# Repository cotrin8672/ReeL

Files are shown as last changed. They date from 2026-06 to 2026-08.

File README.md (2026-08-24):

# ReeL

Hardware sources and manufacturing assets for the ReeL split keyboard.

The RMK firmware, Vial definition, trackball profiler, and firmware build
workflow live in [rmk-config-ReeL](https://github.com/cotrin8672/rmk-config-ReeL).

## Repository layout

- `pcb/`: KiCad projects, project-local symbol and footprint libraries, and the PMW3610 breakout manufacturing package
- `model/`: mechanical STEP and STL models
- `fabrication/gerber/`: generated Gerber and drill outputs for the main left and right PCBs
- `docs/materials/`: component research and supporting material documents

The firmware repository was split from hardware commit
`b9bacc7681b5a1461f23b08cf7a2b1b867c73b0e`.

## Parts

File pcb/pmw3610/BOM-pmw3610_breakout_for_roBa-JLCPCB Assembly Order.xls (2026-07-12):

JLCPCB BOM Tool - BOM Matching
BOM name：BOM-pmw3610_breakout_for_roBa-JLCPCB Assembly Order.xlsx |  |  | Download Time：2026-07-12 19:56:11 |  |  |  | * Our matching results are updated in real-time, but stock and prices may change. If it's been over 24 hours, please re-match before placing your order.
PCB Assembled Qty：5 |  |  | Est. Total Price：3.9725
Your BOM |  |  |  |  | Matched Parts |  |  |  |  |  |  | Order Information
Top Designator | Bottom Designator | Comment | Footprint | JLCPCB Part # | Matches | Part # | Manufacturer | Footprint | Description | Category | Warning | JLCPCB Part # | Product link | Lib Type | Qty | Source | Total Price ($)
 | C1,C2 | 1u | C_0603_1608Metric |  | Select by System | CL10A105KB8NNNC | Samsung Electro-Mechanics | 0603 | 1uF 50V X5R ±10% 0603 Multilayer Ceramic Capacitors MLCC - SMD/SMT ROHS | Multilayer Ceramic Capacitors MLCC - SMD/SMT |  | C15849 | https://jlcpcb.com/partdetail/16531-CL10A105KB8NNNC/C15849 | Basic | 10 | 10 JLCPCB | 0.276
 | C3,C8 | 100n | C_0603_1608Metric |  | Unconfirmed | CC0603KRX7R9BB104 | YAGEO | 0603 | 100nF 50V X7R ±10% 0603 Multilayer Ceramic Capacitors MLCC - SMD/SMT ROHS | Multilayer Ceramic Capacitors MLCC - SMD/SMT | 1.Multiple lines in the BOM have been matched to the same part. Please check if the matching is correct. ; | C14663 | https://jlcpcb.com/partdetail/YAGEO-CC0603KRX7R9BB104/C14663 | Basic | 15 | 15 JLCPCB | 0.402
 | C5 | 100n(X7R) | C_0603_1608Metric |  | Unconfirmed | CC0603KRX7R9BB104 | YAGEO | 0603 | 100nF 50V X7R ±10% 0603 Multilayer Ceramic Capacitors MLCC - SMD/SMT ROHS | Multilayer Ceramic Capacitors MLCC - SMD/SMT | 1.Multiple lines in the BOM have been matched to the same part. Please check if the matching is correct. ; | C14663 | https://jlcpcb.com/partdetail/YAGEO-CC0603KRX7R9BB104/C14663 | Basic | 15 | 15 JLCPCB | 0.402
 | C4 | 10n | C_0603_1608Metric |  | Unconfirmed | 0603B103K500NT | FH (Guangdong Fenghua Advanced Tech) | 0603 | 10nF 50V X7R ±10% 0603 Multilayer Ceramic Capacitors MLCC - SMD/SMT ROHS | Multilayer Ceramic Capacitors MLCC - SMD/SMT | 1.Multiple lines in the BOM have been matched to the same part. Please check if the matching is correct. ; | C57112 | https://jlcpcb.com/partdetail/58143-0603B103K500NT/C57112 | Basic | 10 | 10 JLCPCB | 0.271
 | C7 | 10n(X7R) | C_0603_1608Metric |  | Unconfirmed | 0603B103K500NT | FH (Guangdong Fenghua Advanced Tech) | 0603 | 10nF 50V X7R ±10% 0603 Multilayer Ceramic Capacitors MLCC - SMD/SMT ROHS | Multilayer Ceramic Capacitors MLCC - SMD/SMT | 1.Multiple lines in the BOM have been matched to the same part. Please check if the matching is correct. ; | C57112 | https://jlcpcb.com/partdetail/58143-0603B103K500NT/C57112 | Basic | 10 | 10 JLCPCB | 0.271
 | C6 | 10u(X7R) | C_0603_1608Metric |  | Select by System | CL10A106MA8NRNC | Samsung Electro-Mechanics | 0603 | 10uF 25V X5R ±20% 0603 Multilayer Ceramic Capacitors MLCC - SMD/SMT ROHS | Multilayer Ceramic Capacitors MLCC - SMD/SMT |  | C96446 | https://jlcpcb.com/partdetail/97651-CL10A106MA8NRNC/C96446 | Basic | 5 | 5 JLCPCB | 0.6935
 | C9 | 3.3u/25V | C_0603_1608Metric |  | Select by Customer | CL10A475KO8NNNC | Samsung Electro-Mechanics | 0603 | 16V 4.7uF X5R ±10% 0603 Multilayer Ceramic Capacitors MLCC - SMD/SMT ROHS | Multilayer Ceramic Capacitors MLCC - SMD/SMT |  | C19666 | https://jlcpcb.com/partdetail/20375-CL10A475KO8NNNC/C19666 | Basic | 5 | 5 JLCPCB | 0.5615
 | R1 | 2M | R_0603_1608Metric |  | Select by System | 0603WAF2004T5E | UNI-ROYAL(Uniroyal Elec) | 0603 | -55℃~+155℃ 100mW 2MΩ 75V Thick Film Resistor ±1% ±100ppm/℃ 0603 Chip Resistor - Surface Mount ROHS | Chip Resistor - Surface Mount |  | C22976 | https://jlcpcb.com/partdetail/23703-0603WAF2004T5E/C22976 | Basic | 5 | 5 JLCPCB | 0.014
 | U1 | MCP1700T-1802E/TT | SOT-23 |  | Select by Customer | MCP1700T-1802E/TT(MS) | MSKSEMI | SOT-23 | -40℃~+125℃@(Tj) 1 1.8V 280mV@(300mA) 2uA 300mA 5.5V Fixed Over Current Protection、Over Temperature Protection Positive SOT-23 Voltage Regulators - Linear, Low Drop Out (LDO) Regulators ROHS | Voltage Regulators - Linear, Low Drop Out (LDO) Regulators |  | C20627192 | https://jlcpcb.com/partdetail/MSKSEMI-MCP1700T_1802E_TT_MS/C20627192 | Extended | 7 | 7 JLCPCB | 1.0815

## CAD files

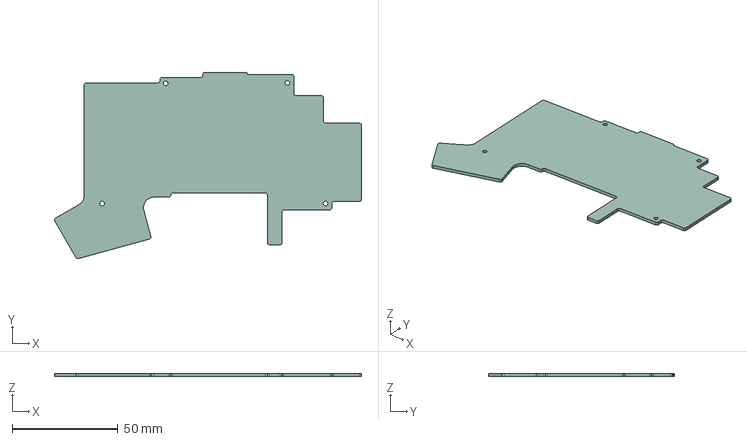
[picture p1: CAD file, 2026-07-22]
hardware/models/reel-right-bottom.step
145.0 x 88.1 x 1.55 mm

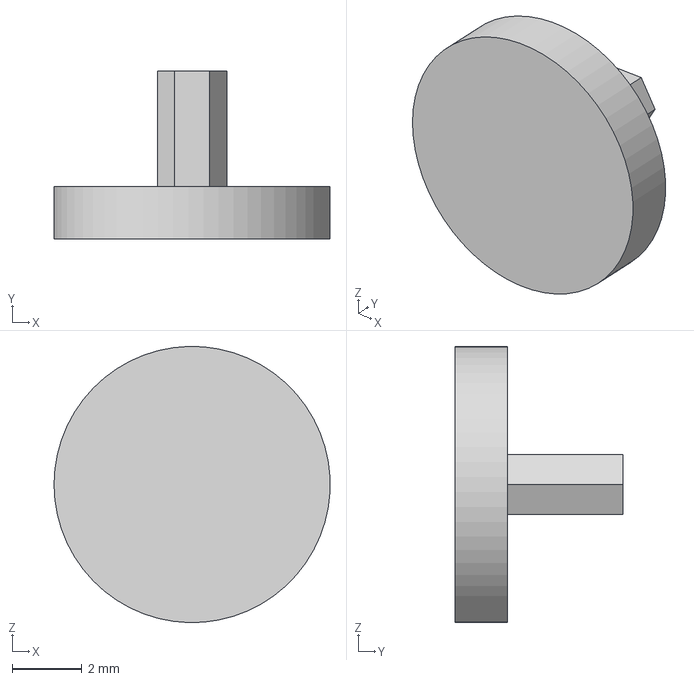
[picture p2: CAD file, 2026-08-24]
model/encoder_knob_3.3.step
7.89 x 4.80 x 7.90 mm

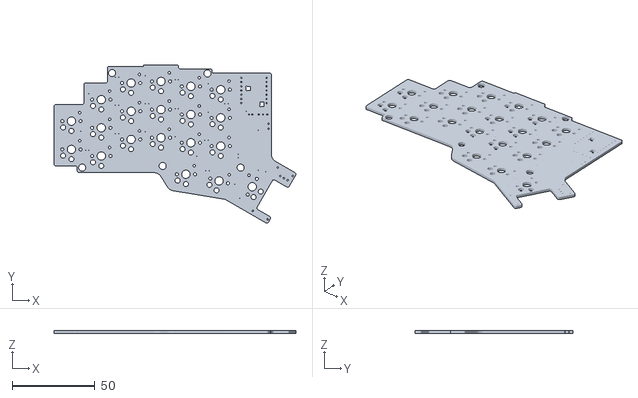
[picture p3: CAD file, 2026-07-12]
pcb/left/ReeL_left.stl
145.9 x 95.5 x 1.60

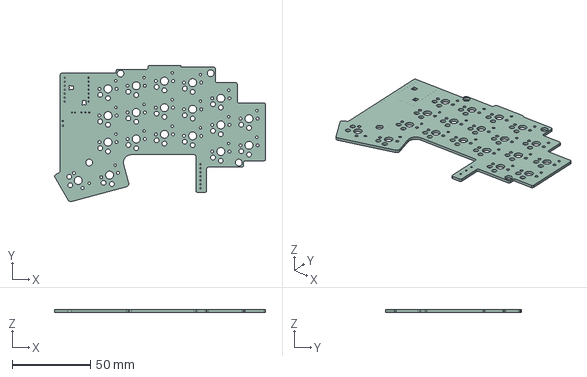
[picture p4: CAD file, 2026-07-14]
pcb/right/ReeL_right.step
134.6 x 86.9 x 1.60 mm

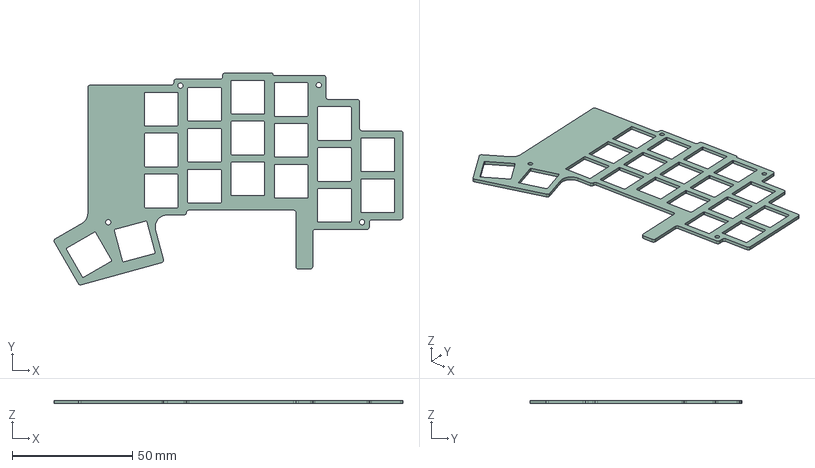
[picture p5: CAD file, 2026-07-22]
hardware/models/reel-right-top.step
145.0 x 88.1 x 1.45 mm

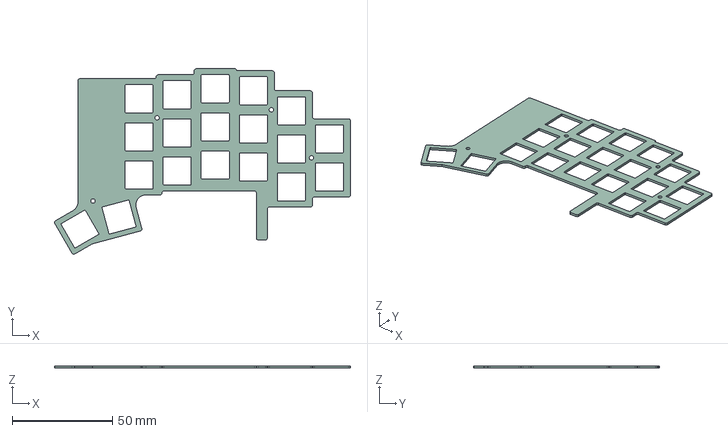
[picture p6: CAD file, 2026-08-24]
model/reel_right_top.step
147.7 x 92.6 x 1.20 mm

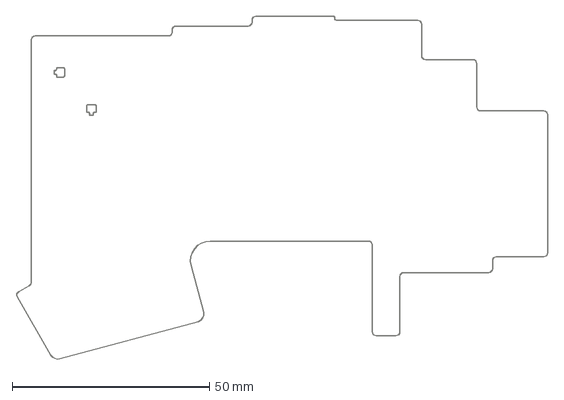
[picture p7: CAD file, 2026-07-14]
pcb/right/reel-right-Edge_Cuts.dxf
134.8 x 87.1 mm

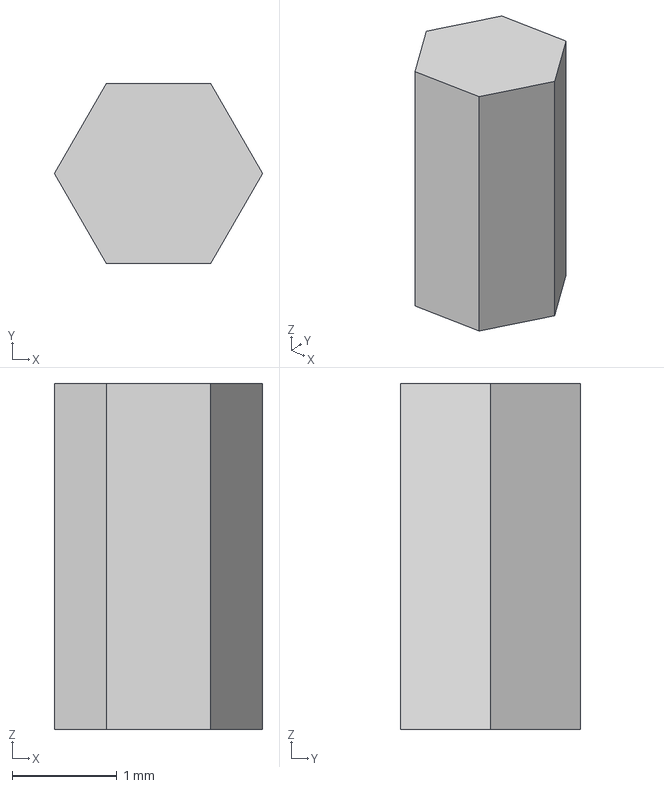
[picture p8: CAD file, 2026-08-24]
model/encoder_pole.step
1.99 x 1.72 x 3.30 mm

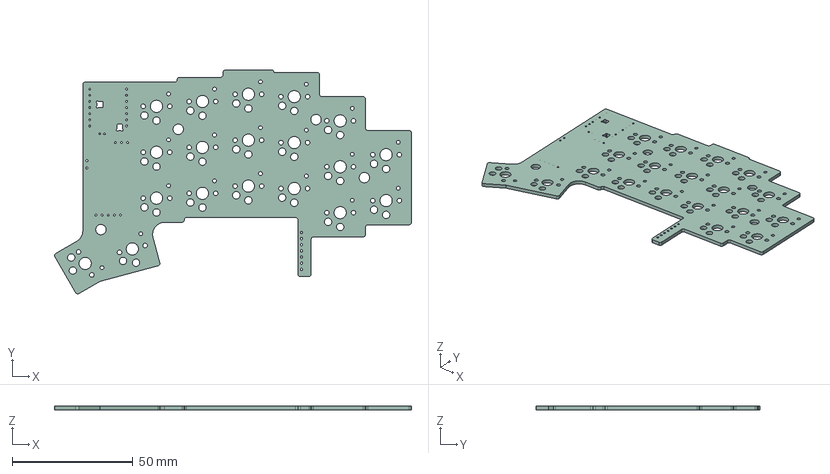
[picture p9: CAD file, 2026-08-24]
model/reel_right.step
147.7 x 92.6 x 1.60 mm

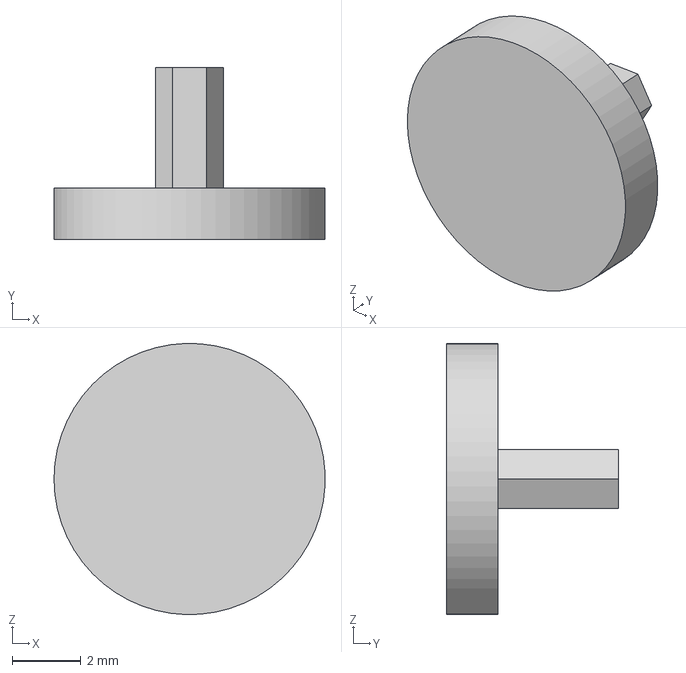
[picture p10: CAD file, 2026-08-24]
model/encoder_knob.step
7.89 x 5.00 x 7.90 mm

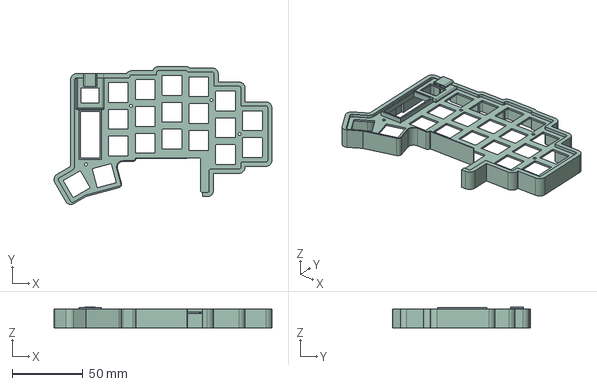
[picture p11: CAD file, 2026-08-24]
model/reel_right_sw.step
154.5 x 97.8 x 14.6 mm

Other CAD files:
pcb/right_bottom/reel_right_bottom.stl
pcb/right_top/reel_right_top.stl
model/reel_right_top_neo.step
model/RotaryEncoderTest.stl
model/TrackballCase.stl
model/encoder_shaft.step
model/reel_left.step
model/reel_left_bottom.step
model/reel_left_top.step
model/reel_right_bottom.step
model/reel_right_top_neo2.step
pcb/right/ReeL_right.stl

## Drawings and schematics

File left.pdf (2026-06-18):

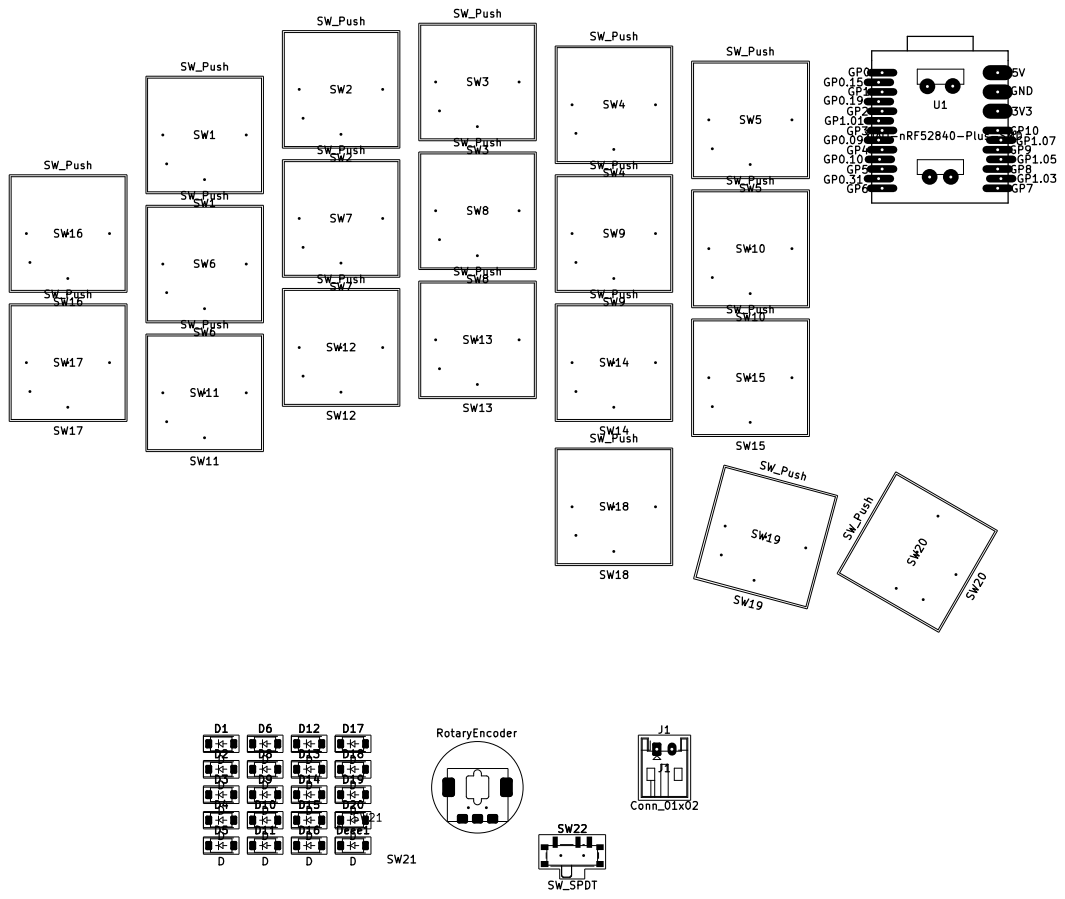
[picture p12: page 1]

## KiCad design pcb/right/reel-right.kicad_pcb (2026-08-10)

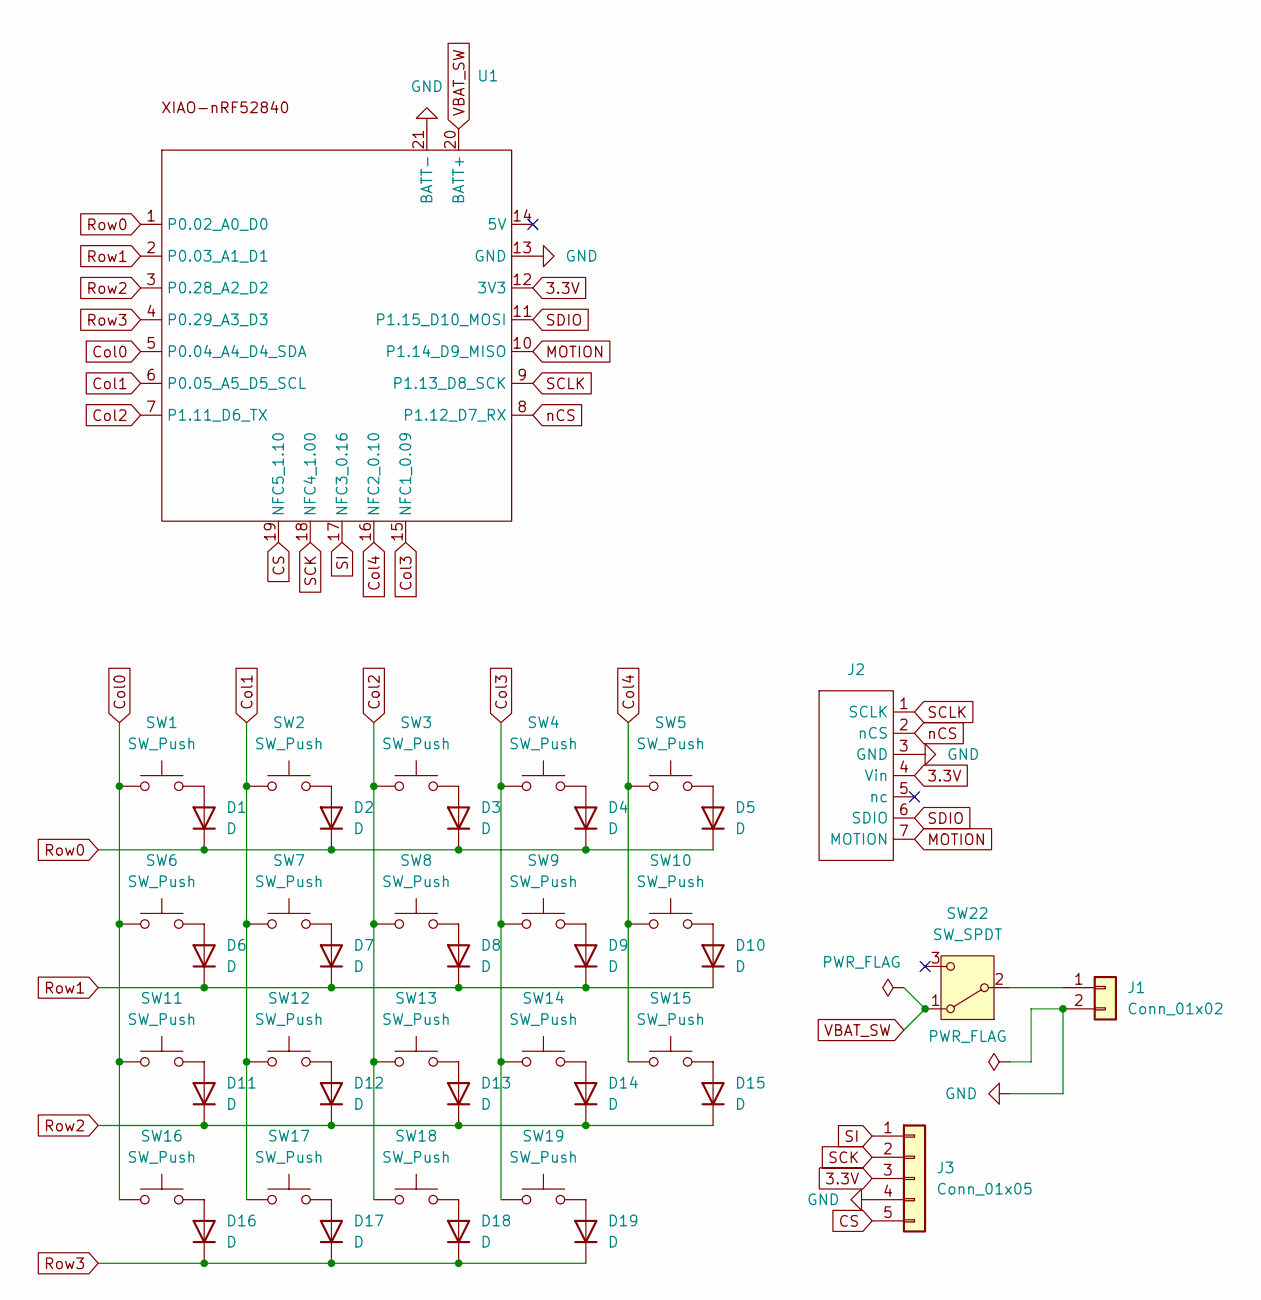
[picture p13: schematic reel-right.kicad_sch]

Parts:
D1, D2, D3, D4, D5, D6, D7, D8, D9, D10, D11, D12, D13, D14, D15, D16, D17, D18, D19: D; Diode_SMD
J1: Conn_01x02; JST_PH_S2B-PH-K_1x02_P2.00mm_Horizontal
J2: pmw3610_connector
J3: Conn_01x05; Display_BeeKeeb_MIP_1.08in_LS011B7DH03
SW1, SW2, SW3, SW4, SW5, SW6, SW7, SW8, SW9, SW10, SW11, SW12, SW13, SW14, SW15, SW16, SW17, SW18, SW19: SW_Push; SW_Hotswap_Kailh_Choc_V1V2_1.00u
SW22: SW_SPDT; SW_SPDT_PCM12
U1: XIAO_nRF52840_wBAT_wNFC_1

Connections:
3.3V: J2.4 (Vin), J3.3, U1.12 (3V3)
CS: J3.5, U1.19 (NFC5_1.10)
Col0: SW1.1, SW6.1, SW11.1, SW16.1, U1.5 (P0.04_A4_D4_SDA)
Col1: SW2.1, SW7.1, SW12.1, SW17.1, U1.6 (P0.05_A5_D5_SCL)
Col2: SW3.1, SW8.1, SW13.1, SW18.1, U1.7 (P1.11_D6_TX)
Col3: SW4.1, SW9.1, SW14.1, SW19.1, U1.15 (NFC1_0.09)
Col4: SW5.1, SW10.1, SW15.1, U1.16 (NFC2_0.10)
GND: J1.2, J2.3 (GND), J3.4, U1.13 (GND), U1.21 (BATT-)
MOTION: J2.7 (MOTION), U1.10 (P1.14_D9_MISO)
unnamed: D1.2 (A), SW1.2
unnamed: D2.2 (A), SW2.2
unnamed: D3.2 (A), SW3.2
unnamed: D4.2 (A), SW4.2
unnamed: D5.2 (A), SW5.2
unnamed: D6.2 (A), SW6.2
unnamed: D7.2 (A), SW7.2
unnamed: D8.2 (A), SW8.2
unnamed: D9.2 (A), SW9.2
unnamed: D10.2 (A), SW10.2
unnamed: D11.2 (A), SW11.2
unnamed: D12.2 (A), SW12.2
unnamed: D13.2 (A), SW13.2
unnamed: D14.2 (A), SW14.2
unnamed: D15.2 (A), SW15.2
unnamed: D16.2 (A), SW16.2
unnamed: D17.2 (A), SW17.2
unnamed: D18.2 (A), SW18.2
unnamed: D19.2 (A), SW19.2
unnamed: J1.1, SW22.2 (B)
Row0: D1.1 (K), D2.1 (K), D3.1 (K), D4.1 (K), D5.1 (K), U1.1 (P0.02_A0_D0)
Row1: D6.1 (K), D7.1 (K), D8.1 (K), D9.1 (K), D10.1 (K), U1.2 (P0.03_A1_D1)
Row2: D11.1 (K), D12.1 (K), D13.1 (K), D14.1 (K), D15.1 (K), U1.3 (P0.28_A2_D2)
Row3: D16.1 (K), D17.1 (K), D18.1 (K), D19.1 (K), U1.4 (P0.29_A3_D3)
SCK: J3.2, U1.18 (NFC4_1.00)
SCLK: J2.1 (SCLK), U1.9 (P1.13_D8_SCK)
SDIO: J2.6 (SDIO), U1.11 (P1.15_D10_MOSI)
SI: J3.1, U1.17 (NFC3_0.16)
VBAT_SW: SW22.1 (A), U1.20 (BATT+)
nCS: J2.2 (nCS), U1.8 (P1.12_D7_RX)

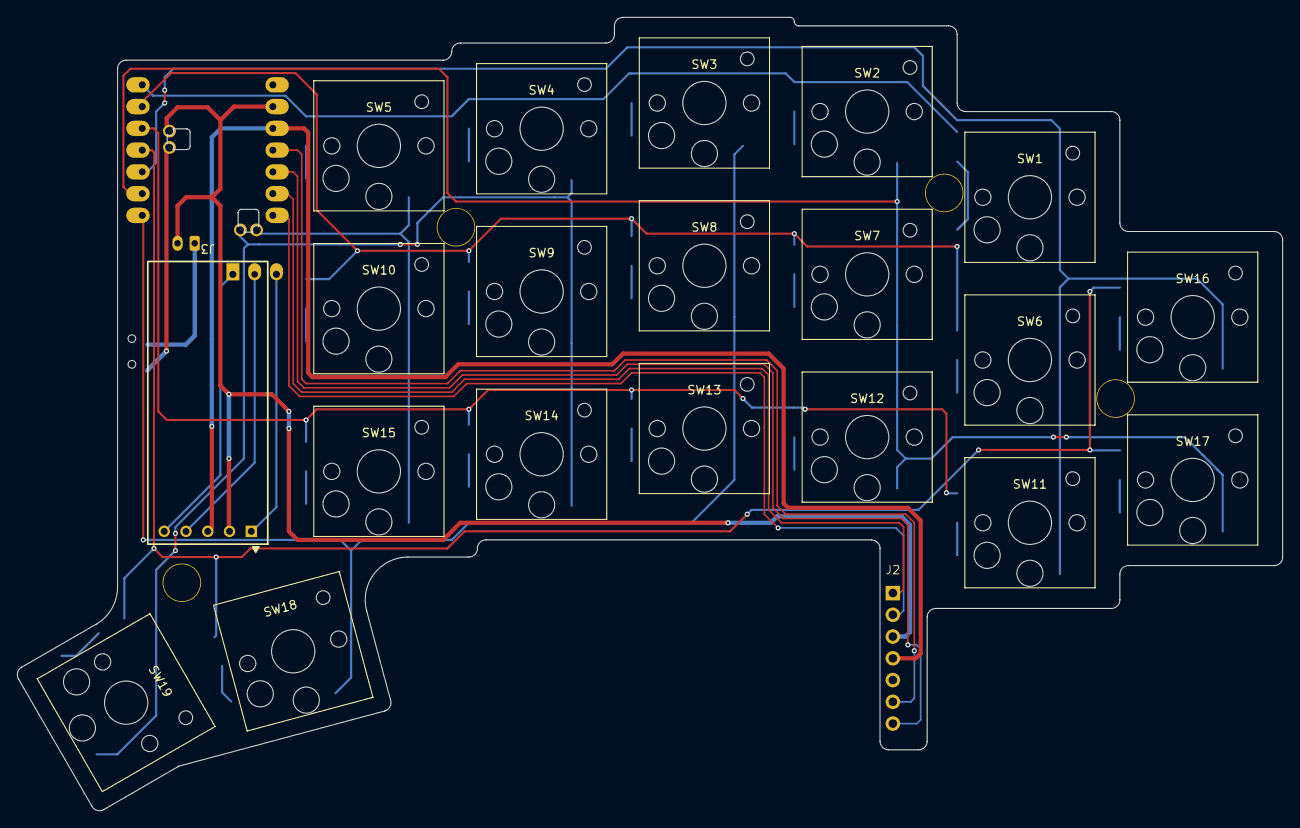
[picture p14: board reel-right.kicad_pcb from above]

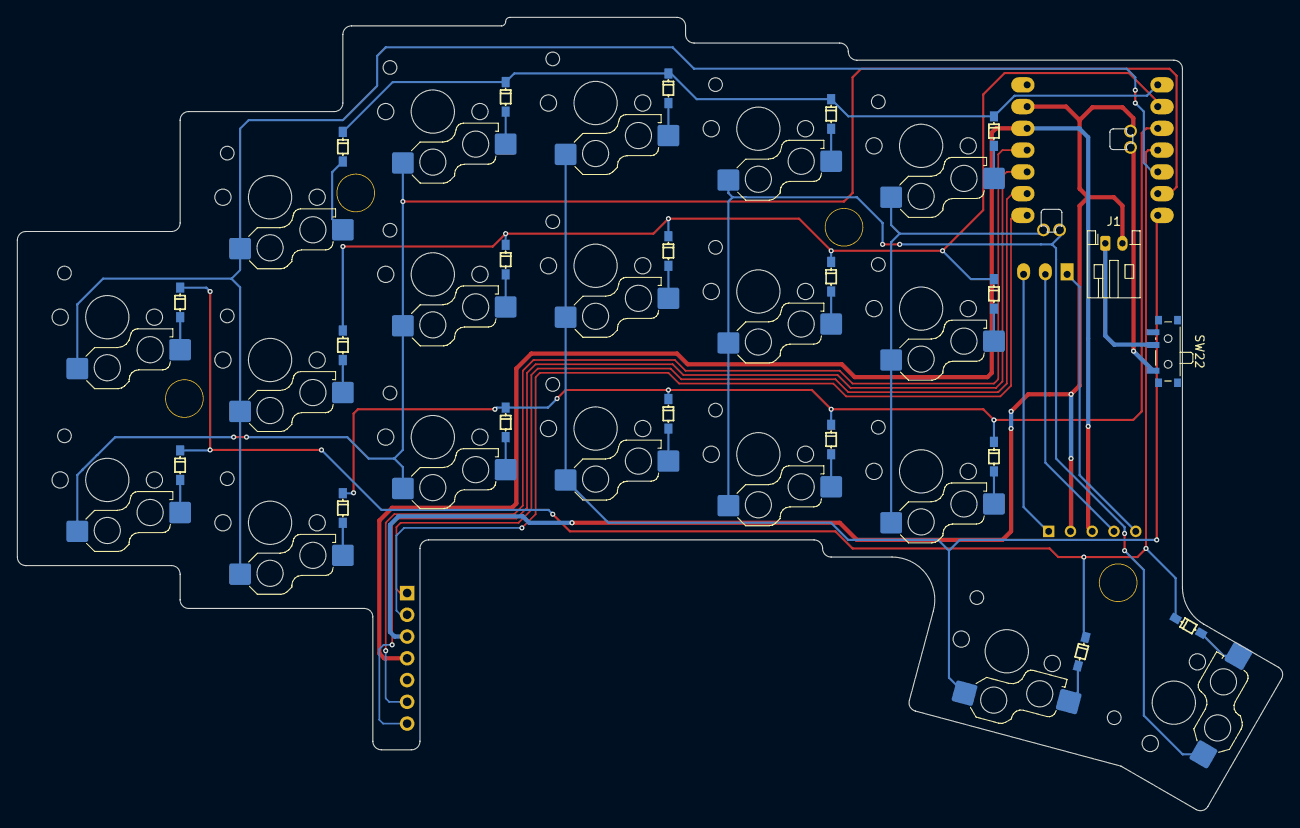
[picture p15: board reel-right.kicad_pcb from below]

Board: 2 copper layers, 147.7 x 92.6 mm, 47 parts (2 on the bottom side), 39 nets.

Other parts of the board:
Ref**: Val**; m2_Spacer_Hole
Ref**#2, Ref**#3, Ref**#4: Val**; m2_Spacer_Hole

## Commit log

2026-06-17 change matrix and add rotary encoder in scketch
    [corbit.kicad_sch]
2026-06-17 generated PCB
    [corbit.kicad_pcb, corbit.kicad_sch]
2026-06-18 edit pcb
    [corbit.kicad_pcb, corbit.kicad_sch]
2026-06-18 edit outline
    [corbit.kicad_pcb]
2026-06-27 Update left board encoder footprint
    [ReeL_left.stl, reel-left.kicad_pcb, reel-left.kicad_sch]
2026-06-27 Update left board assets
    [EncoderKnob.stl, ReeL_left.stl, reel-left.kicad_pcb]
2026-07-05 Update left PCB layout
    [reel-left.kicad_pcb, reel-left.kicad_sch]
2026-07-07 Update ReeL KiCad libraries and board
    [reel-left.kicad_pcb, reel-left.kicad_sch, reel-right.kicad_sch]
2026-07-07 Ignore KiCad backup archives
2026-07-07 Update ReeL KiCad board files
    [reel-left.kicad_pcb, reel-left.kicad_sch, reel-right.kicad_pcb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]
2026-07-08 Update PCB layouts and fabrication outputs
    [reel-left.kicad_pcb, reel-right.kicad_pcb]
2026-07-08 Route right Col3 trace
    [reel-right.kicad_pcb]
2026-07-09 Add top board projects and STL exports
    [ReeL_left_board_0.75mm.stl, ReeL_right_board_0.75mm.stl, reel-left-top.kicad_pcb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]
2026-07-10 Update ReeL switch footprints and board layouts
    [reel-left.kicad_pcb, reel-left.kicad_sch, reel-right.kicad_pcb]
2026-07-11 Update right board fabrication outputs
    [ReeL_right.step, ReeL_right.stl, TrackballCase.stl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]
2026-07-12 Update left board and rotary encoder fabrication assets
    [BOM-pmw3610_breakout_for_roBa-JLCPCB Assembly Order.xls, EncoderKnob.stl, EncoderShaft.stl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]
2026-07-12 Add BeeKeeb 1.08-inch MIP LCD footprint
2026-07-13 Reorganize hardware and add ZMK firmware
    [BOM-pmw3610_breakout_for_roBa-JLCPCB Assembly Order.xls, EncoderKnob.stl, EncoderShaft.stl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]
2026-07-14 Update PCB layouts and mechanical assets
    [ReeL_right.step, reel-left.kicad_pcb, reel-left.kicad_sch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]
2026-07-15 Add right-bottom PCB fabrication assets
    [EncoderKnob.stl, RotaryEncoderTest.stl, reel-right-bottom-Edge_Cuts.dxf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]
2026-07-17 Add right-bottom plate PCB and STEP model
    [reel-right-bottom.kicad_pcb, reel_right_bottom.step]
2026-07-19 Update ReeL hardware and fabrication assets
    [EncoderKnob.step, EncoderKnob.stl, EncoderShaft.step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]
2026-07-20 Update right plate PCB models
    [EncoderKnob.step, EncoderShaft.step, reel-right-bottom.kicad_pcb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]
2026-07-22 Update right PCB and derived variants
    [reel-right-bottom.kicad_pcb, reel-right-top.kicad_pcb, reel-right.kicad_pcb]
2026-07-22 Refresh fabrication and mechanical outputs
    [EncoderKnob.step, EncoderShaft.step, ReeL_left_board_0.75mm.stl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]
2026-07-22 Add top and bottom PCB plate templates
    [reel_left_bottom.kicad_pcb, reel_left_bottom.kicad_sch, reel_left_bottom.stl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]
2026-07-22 Update ReeL firmware for current PCB
2026-07-30 Apply calibrated trackball axis transform
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2026-07-30 Update hardware assets and trackball profiler
    [EncoderKnob.step, EncoderShaft.step, reel-left-top.kicad_pcb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]
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2026-07-31 Fix left rotary encoder decoding
2026-07-31 Restore encoder scrolling and reverse direction
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2026-07-31 Update mechanical models and trackball profiler
    [reel_left_bottom.step, reel_left_top.step, reel_right_bottom.step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]
2026-07-31 Fix XIAO battery divider ratio
2026-08-07 Adjust right PCB edge and trackball routing
    [reel-right.kicad_pcb]
2026-08-08 Update PCB routing and mechanical models
    [reel-left.kicad_pcb, reel_left.step, reel_left_bottom.step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]
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2026-08-08 Update PCB and side switch research
    [reel-right.kicad_pcb, side_push_smd_switches_20260718.xlsx]
2026-08-09 Update ReeL PCB and mechanical assets
    [reel-left.kicad_pcb, reel-right.kicad_pcb, reel_left_bottom.kicad_pcb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]
2026-08-10 Correct ReeL PCB connector pinouts and routing
    [reel-left.kicad_pcb, reel-left.kicad_sch, reel-right.kicad_pcb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]
2026-08-10 Regenerate ReeL Gerber fabrication outputs
    [reel-left-B_Cu.gbr, reel-left-B_Mask.gbr, reel-left-B_Paste.gbr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]
2026-08-10 Update left and right PCB routing
    [reel-left.kicad_pcb, reel-right.kicad_pcb]
2026-08-10 Regenerate PCB fabrication outputs
    [reel-left-B_Cu.gbr, reel-left-B_Mask.gbr, reel-left-B_Paste.gbr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]
2026-08-10 Regenerate top and bottom plate projects
    [reel_left_bottom.kicad_pcb, reel_left_bottom.kicad_sch, reel_left_top.kicad_pcb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]
2026-08-10 Update plate mechanical models
    [reel_left_bottom.step, reel_left_top.step, reel_right_bottom.step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]
2026-08-14 Add LCD status firmware and update project assets
    [reel-left.kicad_pcb, reel_left_bottom.step, reel_left_top.step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]
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2026-08-15 Replace LCD circle with battery outline
2026-08-16 Update ReeL hardware assets and firmware
    [EncoderKnob.step, encoder_knob.step, encoder_shaft.step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]
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2026-08-17 Fix Vial thumb cluster and encoder layout
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2026-08-17 Fix encoder and thumb layout
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2026-08-17 Fix rotary encoder detent handling
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2026-08-17 Fix rotary encoder event delivery
2026-08-17 Revert "Fix rotary encoder event delivery"
    This reverts commit e26f6cd2f41b2c4bff7b11703efd5fa8d2feffa2.
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2026-08-18 Fix sluggish trackball reporting
    [reel_right_bottom.step]
2026-08-18 Fix left rotary encoder quadrature decoding
2026-08-19 Fix rotary encoder detent threshold
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2026-08-23 Fix rotary encoder decoding for BM4.0A01 signals
    Use debounced phase A edges for one event per detent and derive direction from signed Gray-code movement around each edge, avoiding the unstable fixed-time phase B reads that caused missed clicks and alternating directions. Cover bounce, fast rotation, and immediate reversals with host-side waveform tests.
2026-08-23 Raise trackball report rate and handle fast motion
    Report PMW3610 motion at 250 Hz, apply per-profile CPI changes through PointingSetCpiEvent, and drain oversized axis samples immediately so fast flicks do not replay stale motion across report period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
2026-08-23 Revert accidental KiCad export config change
    Drop the unrelated step export field added to reel-right.kicad_pro in the trackball commit.
2026-08-24 Publish current hardware and fabrication assets
    [EncoderKnob.step, EncoderShaft.step, encoder_knob.step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]
2026-08-24 Separate hardware from RMK firmware
    [BOM-pmw3610_breakout_for_roBa-JLCPCB Assembly Order.xls, ReeL_left.stl, ReeL_right.step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]
2026-08-24 Update encoder knob models and remove obsolete material
    [encoder_knob_3.3.step, side_push_smd_switches_20260718.xlsx]
